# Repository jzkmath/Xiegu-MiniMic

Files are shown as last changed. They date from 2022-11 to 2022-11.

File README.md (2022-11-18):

# Xiegu-MiniMic
A Small Microphone for the Xiegu G90, X5105 and X6100 Radios. I have designed this to be assembled mostly by JLCPCB. (See below for instructions on how to order them)

After looking at the larger Microphone that comes with the radio, it appears to be a clone of the ICOM HM151 Hand Mic. Knowing this, I was able to use the service manual to create this PCB.

This is designed using KiCad Version 6.0.9

The Enclosure can be 3D Printed and requires 4 M2x20mm Socket Head Screws and 4 M2 Nuts. I used McMaster Carr Part numbers 91292A013 and 90591A111 for this project.

## Version History:

Rev. A: Initial Design

Rev. B: Found that the EM6022P Microphone Element was wired backwards. Fixed it in this revision.

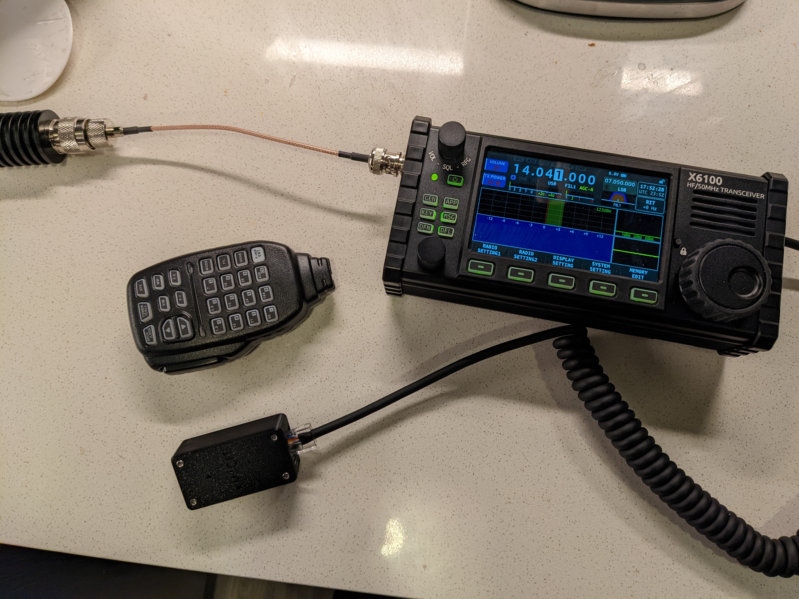
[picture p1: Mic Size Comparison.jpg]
Mic Size Comparison


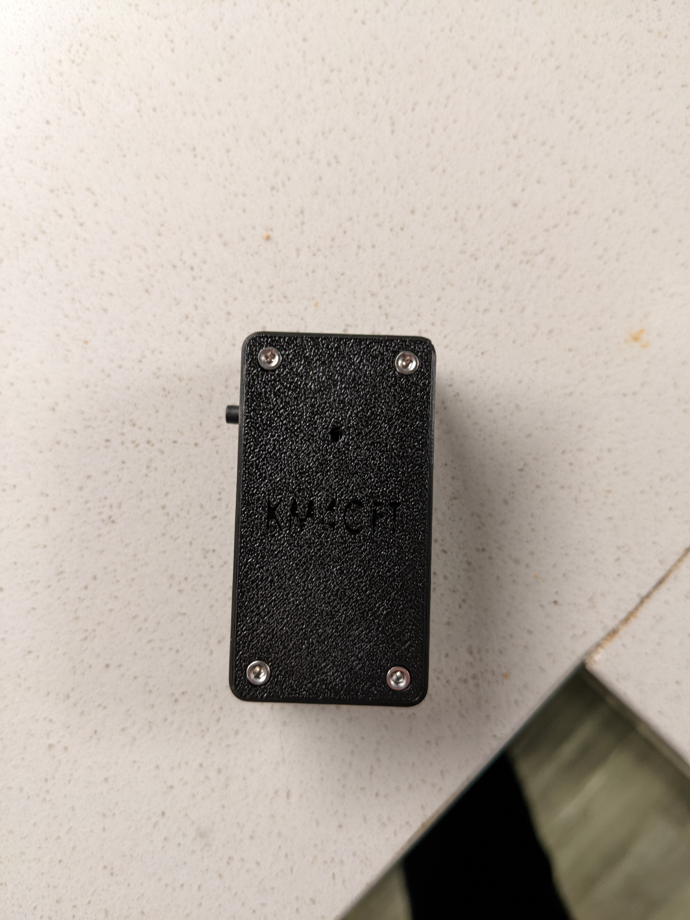
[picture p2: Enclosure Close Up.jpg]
Enclosure Close up


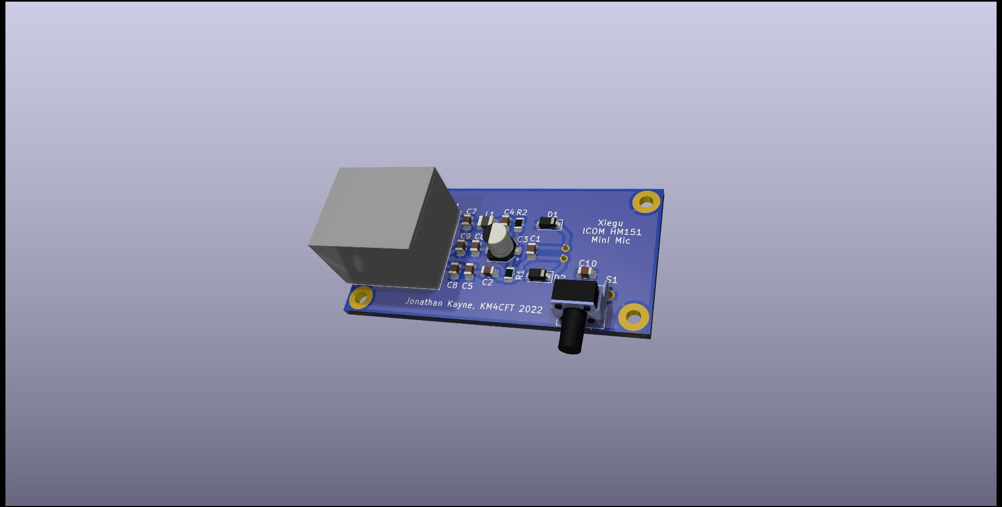
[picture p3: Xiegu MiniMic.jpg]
PCB Render


## PCB Assembly Instructions:

1. Download this repository by clicking on "code" then downloading as a ZIP file. Extract the ZIP file.
2. Go to https://jlcpcb.com/quote
3. Click "Add Gerber File" upload the `Xiegu-MiniMic-GERBER.zip` file found in the `GERBER` folder.
4. Adjust settings. The only ones you should change (if you want) is PCB Qty, PCB Color, and Surface Finish. 
  - If you just want the PCB you may click "Save to Cart" and place your order.
  - If you want assembly, proceed to step 5.
5. Scroll don and tick the slider to the right of "PCB Assembly"
6. Leave it set to "Assemble Top Side" and click "Confirm"
7. For the "BOM File" upload `Xiegu MiniMic.csv` in the `ASSEMBLY` folder.
8. For the "CPL File" upload `Xiegu MiniMic-top-pos.csv` in the `ASSEMBLY` folder.
9. For Usage, I recommend you set it to "Research/Education/DIY/Entertainment > DIY HS Code 902300" (You can really set it to whatever you want)
10. Click "Next"
11. Make sure the BOM is complete (except for the RJ45 connector) 
  - If one of the parts are out of stock, you can substitute with a similar part. 
  - For resistors and capacitors, the main thing to ensure is the value and the case is 0805 (except for C3)
  - C3 is an electrolytic capacitor. Specs needed: 10uF, at least 16V, Diameter: 4mm, Length: 5.4mm (SMD)
  - Zener Diodes are 9.1v, and have a SOD-123 package
  - Inductor L1 is 33uH and has a 1008 package size
12. Once any substitutions are made, click "Next"
13. Inspect the render to make sure the orientation is correct. C3 should have the plus line up and the diodes should have their negative on the right side, matching up with the silkscreen.
14. Click "Add to Cart" then place your order.

You will likely need to order the RJ45 connector (54602-908LF) and microphone (EM6022P) from Digikey or Mouser and solder them yourself.

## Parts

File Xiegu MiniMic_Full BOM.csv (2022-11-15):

Item | Qty | Reference(s) | Value | LibPart | Footprint | Digikey PN | LCSC | MPN | Manufacturer
1 | 1 | C1 | 470pF | Device:C | Capacitor_SMD:C_0805_2012Metric | 478-1324-1-ND | C1743 | 08055A471JAT2A | KYOCERA AVX
2 | 1 | C2 | 1uF | Device:C | Capacitor_SMD:C_0805_2012Metric | 478-5034-1-ND | C28323 | 0805YC105KAT2A | KYOCERA AVX
3 | 1 | C3 | 10uF | Device:C_Polarized_US | Capacitor_SMD:CP_Elec_4x5.4 | 493-2173-1-ND | C445074 | UWT1C100MCL1GB | Nichicon
4 | 3 | C4, C5, C6 | 22pF | Device:C | Capacitor_SMD:C_0805_2012Metric | 478-1308-1-ND | C1804 | 08055A220JAT2A | KYOCERA AVX
5 | 2 | C7, C10 | 100nF | Device:C | Capacitor_SMD:C_0805_2012Metric | 478-10836-1-ND | C28233 | 08055C104KAT4A | KYOCERA AVX
6 | 2 | C8, C9 | 4.7nF | Device:C | Capacitor_SMD:C_0805_2012Metric | 478-08055C472K4T4ACT-ND | C1744 | 08055C472K4T4A | KYOCERA AVX
7 | 2 | D1, D2 | MMSZ5239B-7-F | Device:D_Zener_Filled | Diode_SMD:D_SOD-123 | MMSZ5239B-FDICT-ND | C459546 | MMSZ5239B-7-F | Diodes Incorporated
8 | 4 | H1, H2, H3, H4 | M2 | Mechanical:MountingHole_Pad | MountingHole:MountingHole_2.2mm_M2_Pad
9 | 1 | J1 | 54602-908LF | Connector:8P8C | Connector_RJ:RJ45_Amphenol_54602-x08_Horizontal | 609-1046-ND | N/A | 54602-908LF | Amphenol ICC (FCI)
10 | 1 | L1 | 33uH | Device:L | Inductor_SMD:L_1008_2520Metric | 445-16476-1-ND | C295130 | NLV25T-330J-EF | TDK Corporation
11 | 1 | MK1 | EM6022P | Device:Microphone_Condenser | Xiegu MiniMic:EM6022P | 433-1088-ND | N/A | EM-6022P | Soberton Inc.
12 | 2 | R1, R2 | 2.2k | Device:R | Resistor_SMD:R_0805_2012Metric | A106060CT-ND | C2073912 | CRG0805F2K2 | TE Connectivity Passive Product
13 | 1 | S1 | 1-1825027-1 | Xiegu MiniMic:1-1825027-1 | Xiegu MiniMic:SW_1-1825027-1 | 450-1658-ND | C266183 | 1-1825027-1 | TE Connectivity ALCOSWITCH Switches

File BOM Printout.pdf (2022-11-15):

### Xiegu MiniMic BOM

Item | Qty Reference(s) Value | | Digikey PN | LCSC PN | MPN | Manufacturer
1 | 1 C1 | 470pF | 478-1324-1-ND | C1743 | 08055A471JAT2A | KYOCERA AVX
2 | 1 C2 | 1uF | 478-5034-1-ND | C28323 | 0805YC105KAT2A | KYOCERA AVX
3 | 1 C3 | 10uF | 493-2173-1-ND | C445074 | UWT1C100MCL1GB Nichicon
4 | 3 C4, C5, C6 | 22pF | 478-1308-1-ND | C1804 | 08055A220JAT2A | KYOCERA AVX
5 | 2 C7, C10 | 100nF | 478-10836-1-ND | C28233 | 08055C104KAT4A | KYOCERA AVX
6 | 2 C8, C9 | 4.7nF | 478-08055C472K4T4ACT-ND | C1744 | 08055C472K4T4A | KYOCERA AVX
7 | 2 D1, D2 | MMSZ5239B-7-F | MMSZ5239B-FDICT-ND | C459546 | MMSZ5239B-7-F | Diodes Incorporated
9 | 1 J1 | 54602-908LF | 609-1046-ND | N/A | 54602-908LF | Amphenol ICC (FCI)
10 | 1 L1 | 33uH | 445-16476-1-ND | C295130 | NLV25T-330J-EF | TDK Corporation
11 | 1 MK1 | EM6022P | 433-1088-ND | N/A | EM-6022P | Soberton Inc.
12 | 2 R1, R2 | 2.2k | A106060CT-ND | C2073912 | CRG0805F2K2 | TE Connectivity Passive Product
13 | 1 S1 | 1-1825027-1 | 450-1658-ND | C266183 | 1-1825027-1 | TE Connectivity ALCOSWITCH

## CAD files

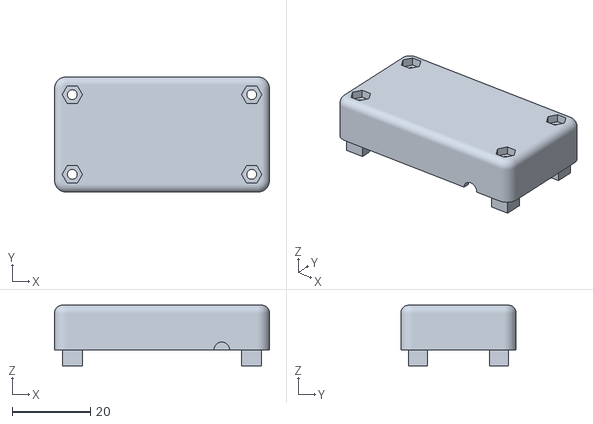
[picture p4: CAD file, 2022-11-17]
Enclosure/Xiegu MiniMic_Top.STL
54.8 x 29.4 x 15.5

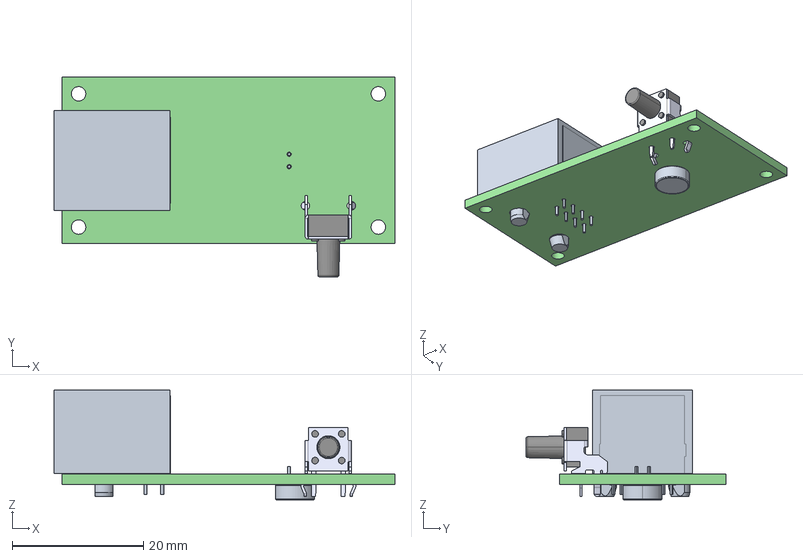
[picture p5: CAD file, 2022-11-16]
Xiegu MiniMic.step
52.0 x 30.4 x 16.7 mm
Xiegu MiniMic PCB

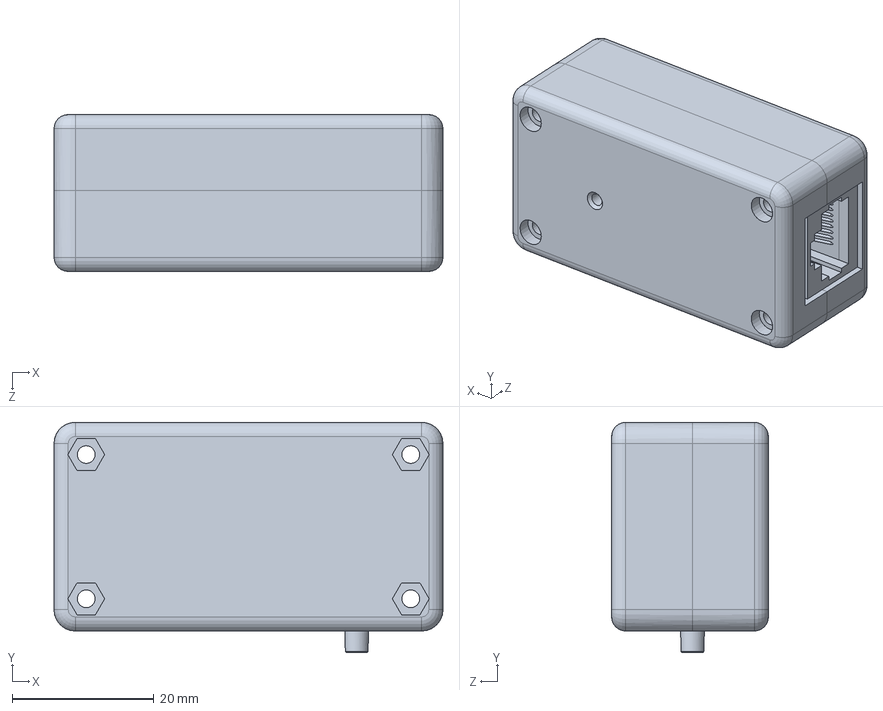
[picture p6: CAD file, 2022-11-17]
Enclosure/Xiegu MiniMic.SLDPRT
54.8 x 32.4 x 22.1 mm

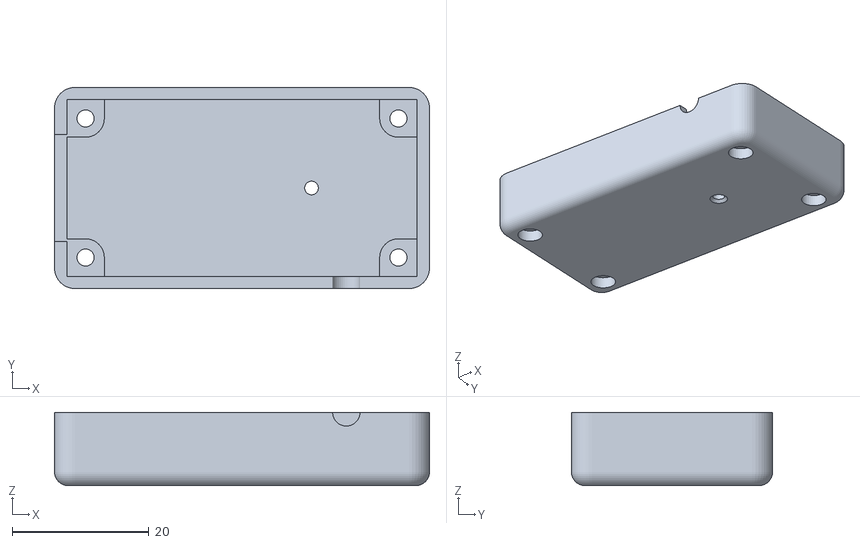
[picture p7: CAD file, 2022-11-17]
Enclosure/Xiegu MiniMic_Bottom.STL
54.8 x 29.4 x 10.7

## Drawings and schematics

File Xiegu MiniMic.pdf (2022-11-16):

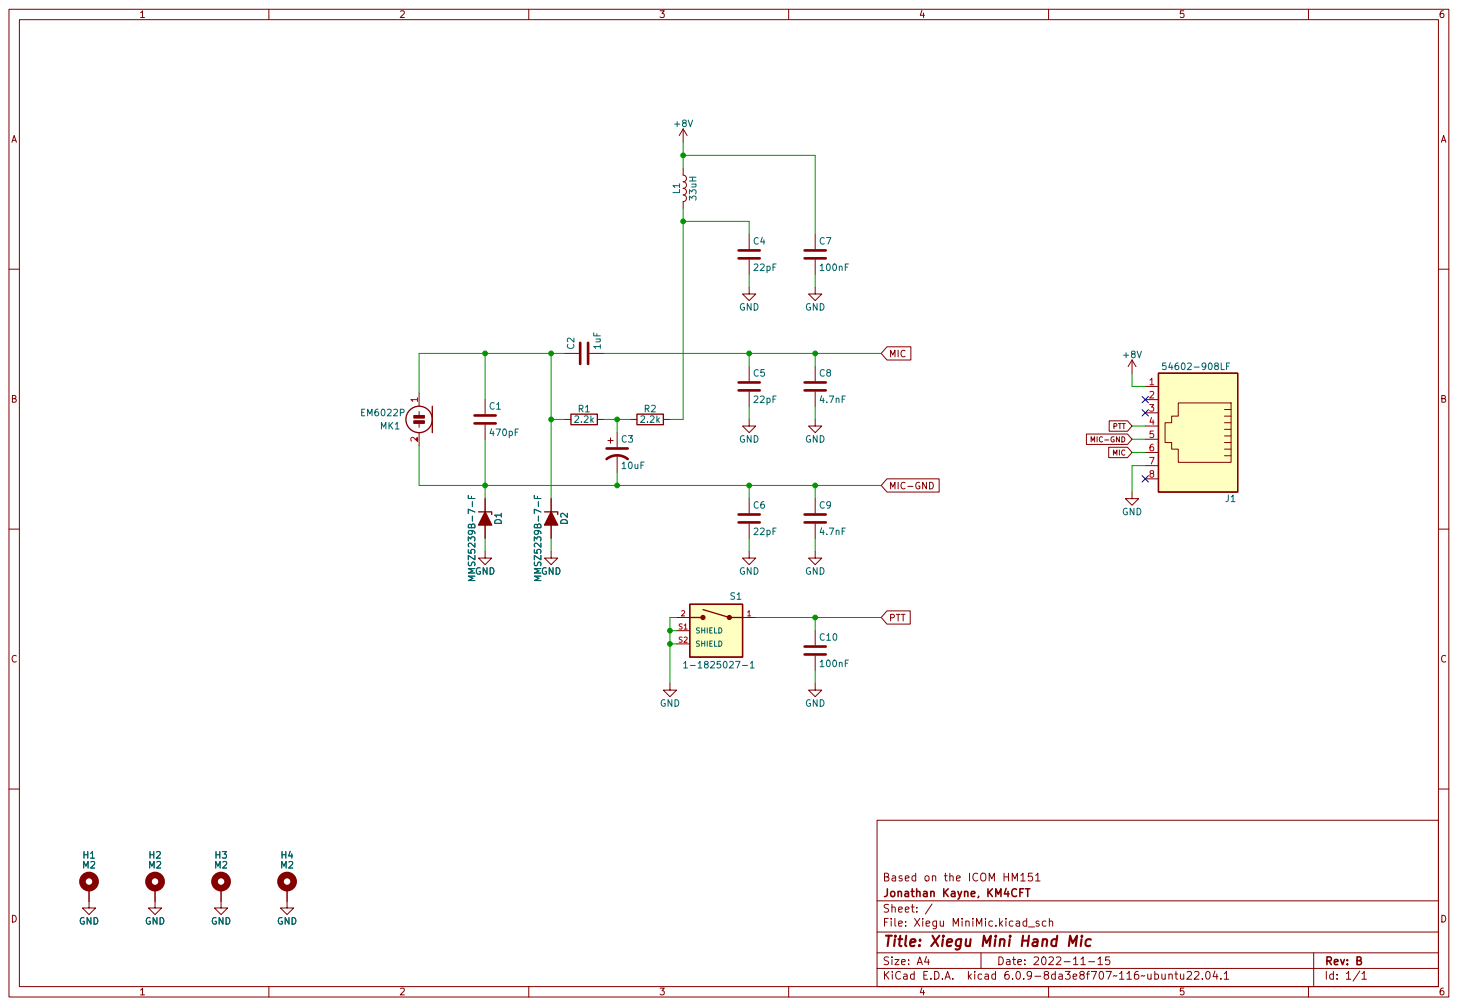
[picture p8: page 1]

PTT MIC-GND MIC

1 2 MK1 EM6022P D1 MMSZ5239B-7-F GND GND GND GND GND GND

Id: 1/1 Title: Xiegu Mini Hand Mic

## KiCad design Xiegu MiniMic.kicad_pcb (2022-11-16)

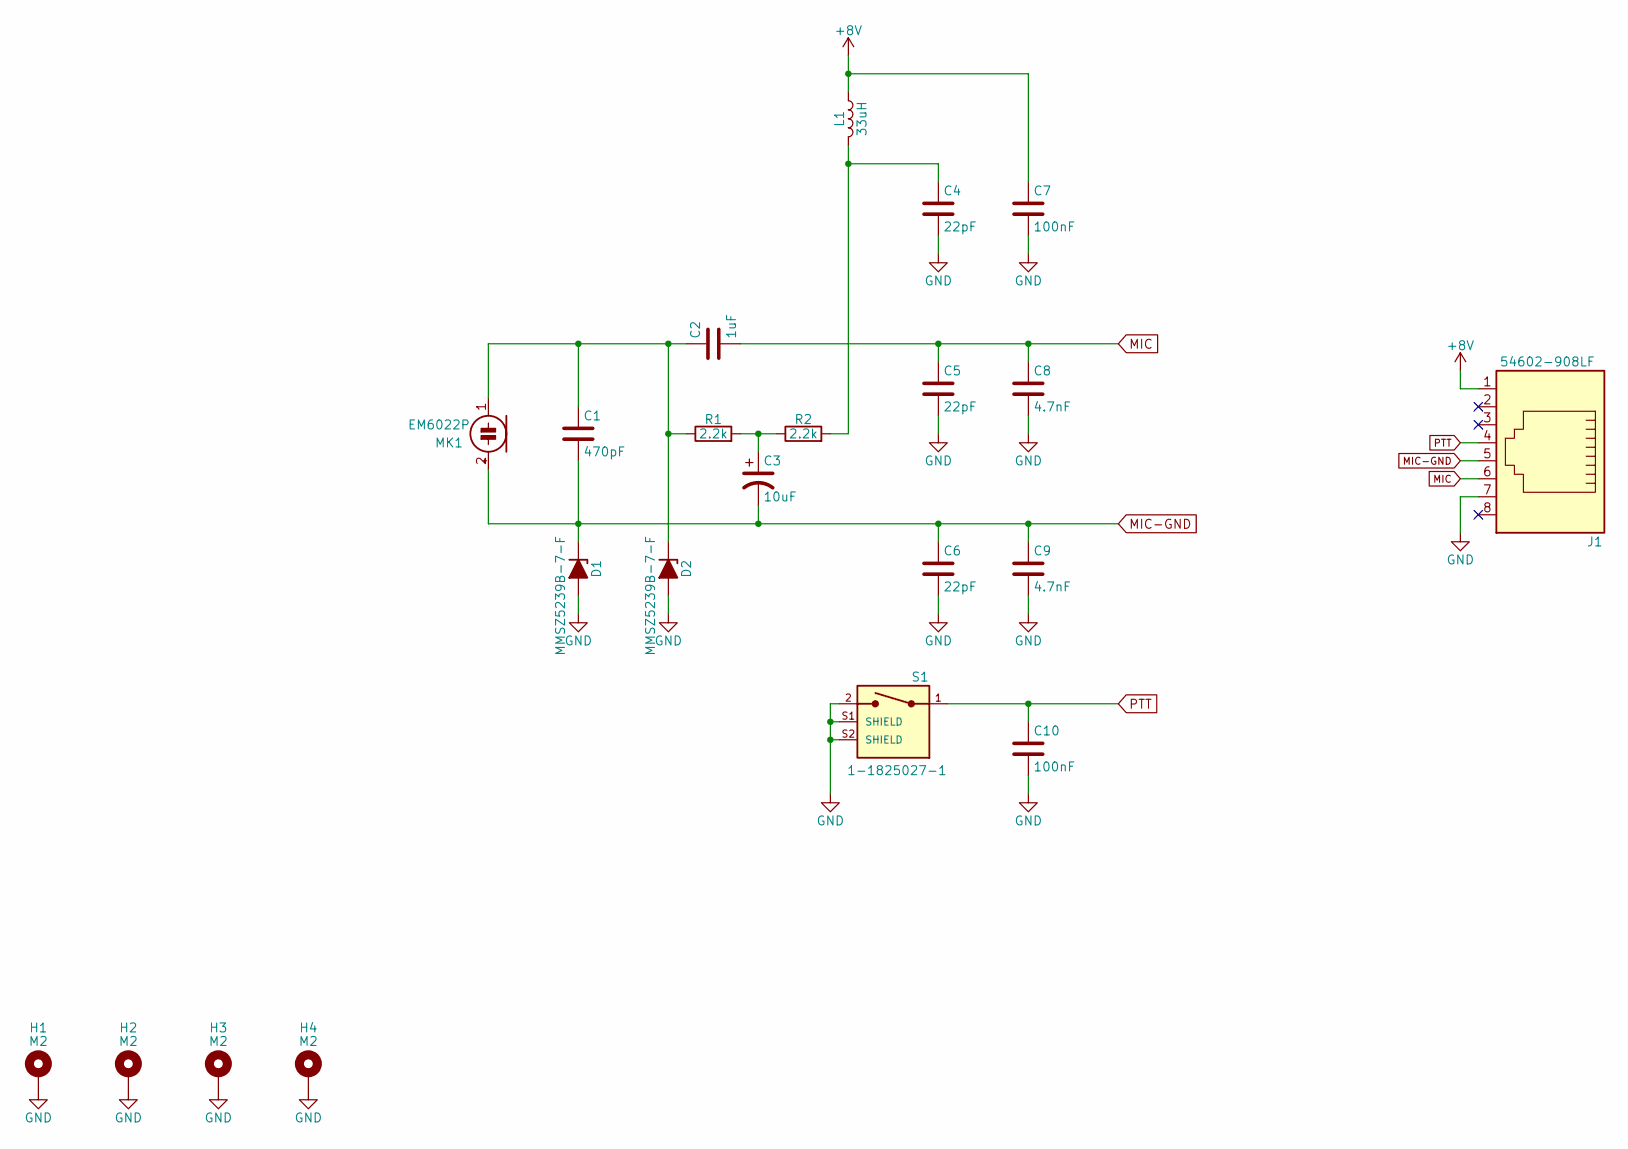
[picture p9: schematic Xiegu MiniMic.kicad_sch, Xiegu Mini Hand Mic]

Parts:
C1: 470pF; C_0805_2012Metric; MPN 08055A471JAT2A; Digikey PN 478-1324-1-ND
C2: 1uF; C_0805_2012Metric; MPN 0805YC105KAT2A; Digikey PN 478-5034-1-ND
C3: 10uF; CP_Elec_4x5.4; MPN UWT1C100MCL1GB; Digikey PN 493-2173-1-ND
C4, C5, C6: 22pF; C_0805_2012Metric; MPN 08055A220JAT2A; Digikey PN 478-1308-1-ND
C7, C10: 100nF; C_0805_2012Metric; MPN 08055C104KAT4A; Digikey PN 478-10836-1-ND
C8, C9: 4.7nF; C_0805_2012Metric; MPN 08055C472K4T4A; Digikey PN 478-08055C472K4T4ACT-ND
D1, D2: MMSZ5239B-7-F; D_SOD-123; MPN MMSZ5239B-7-F; Digikey PN MMSZ5239B-FDICT-ND
H1, H2, H3, H4: M2; MountingHole_2.2mm_M2_Pad
J1: 54602-908LF; RJ45_Amphenol_54602-x08_Horizontal; MPN 54602-908LF; Digikey PN 609-1046-ND
L1: 33uH; L_1008_2520Metric; MPN NLV25T-330J-EF; Digikey PN 445-16476-1-ND
MK1: EM6022P; MPN EM-6022P; Digikey PN 433-1088-ND
R1, R2: 2.2k; R_0805_2012Metric; MPN CRG0805F2K2; Digikey PN A106060CT-ND
S1: 1-1825027-1; SW_1-1825027-1; MPN 1-1825027-1; Digikey PN 450-1658-ND

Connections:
+8V: C7.1, J1.1, L1.1
GND: C4.2, C5.2, C6.2, C7.2, C8.2, C9.2, C10.2, D1.2 (A), D2.2 (A), H1.1, H2.1, H3.1, H4.1, J1.7, S1.2, S1.S1 (SHIELD), S1.S2 (SHIELD)
MIC: C2.2, C5.1, C8.1, J1.6
MIC-GND: C1.2, C3.2, C6.1, C9.1, D1.1 (K), J1.5, MK1.2 (+)
unnamed: C1.1, C2.1, D2.1 (K), MK1.1 (-), R1.1
unnamed: C3.1, R1.2, R2.1
unnamed: C4.1, L1.2, R2.2
PTT: C10.1, J1.4, S1.1

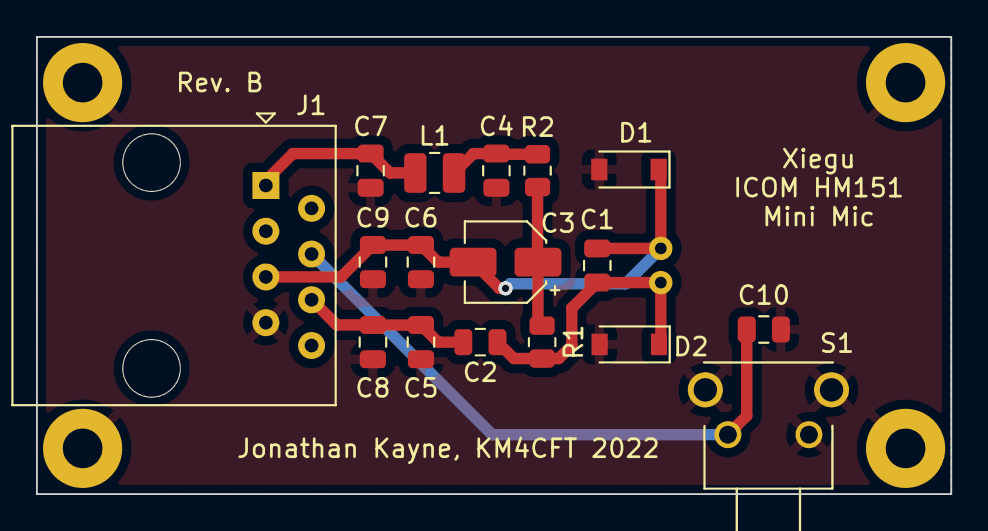
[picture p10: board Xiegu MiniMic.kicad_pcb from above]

Board: 2 copper layers, 50.8 x 25.4 mm, 22 parts (1 on the bottom side), 8 nets.

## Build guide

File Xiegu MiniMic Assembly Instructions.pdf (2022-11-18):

### Xiegu MiniMic Soldering Tips

Jonathan Kayne, KM4CFT
The purpose of this document is to provide some tips and tricks for soldering the Xiegu MiniMic. These will also be useful for any additional Surface-Mount Soldering you may do in the future.
Ultimately, SMD Soldering can be easily performed if you follow these rules:

### 1. More Heat 2. Less Solder 3. Flux is Magic 4. Use Magnification

You will want to have some thin solder, tweezers, a flux pen (I recommend the “no clean” variety) and a cotton swab. Additionally, you may want some type of brush to wipe off the flux residue (no clean flux leaves behind a powder that you can brush off the PCB). The cotton swab is useful because you can use the blunt end of the swab to help the component lie flat.

The process for soldering and SMD component is as follows:
1. Add a small amount of solder to one pad. If possible, avoid starting with the ground pad, since the ground pad requires more heat to solder than a non-grounded pad. Grounded pads have a plus shape on them.
2. Using your tweezers and soldering iron, melt the solder and carefully move the component into place. Try to get it centered if you can!
a) When holding your tweezers, you should avoid holding them like a pencil. You want to “pinch” the tweezers in a way where all 5 fingers are touching it. The advantage to this method is that you can place your fingertips against the table while holding the tweezers and thus make your hand more steady:

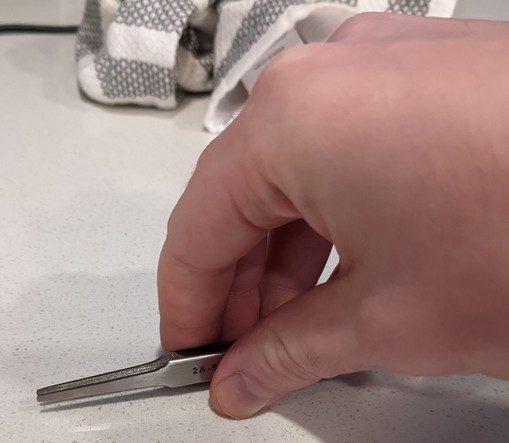
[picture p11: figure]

3. Place the blunt end of the swab on top of the component and reflow the solder. The purpose of this is to make sure that the component is lying flat against the board:

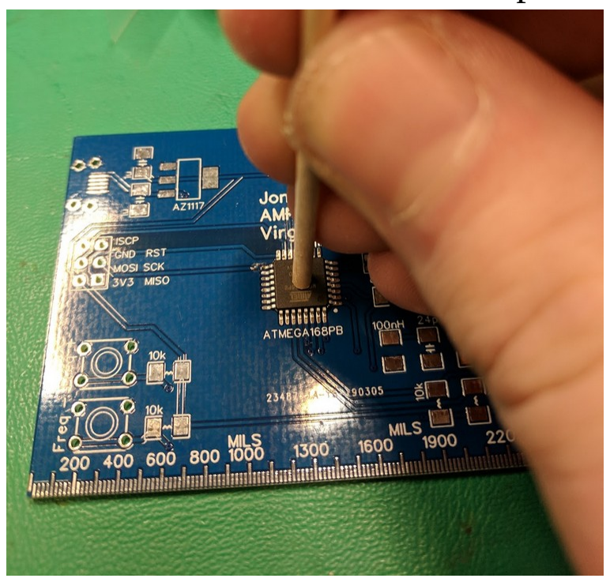
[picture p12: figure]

4. Solder the other pad. Remember rule number 2!
5. Using the flux pen, soak the two ends in flux and reflow the solder. You should observe the flux hiss then the solder melt.
6. (optional) Use a brush to wipe away any flux residue. Once you finish assembly you can also carefully rinse the board in rubbing alcohol to clean away any leftover residue.

### IMPORTANT NOTE:

If your board is Revision A, you will need to solder the EM6022P Microphone element backwards like in this picture:

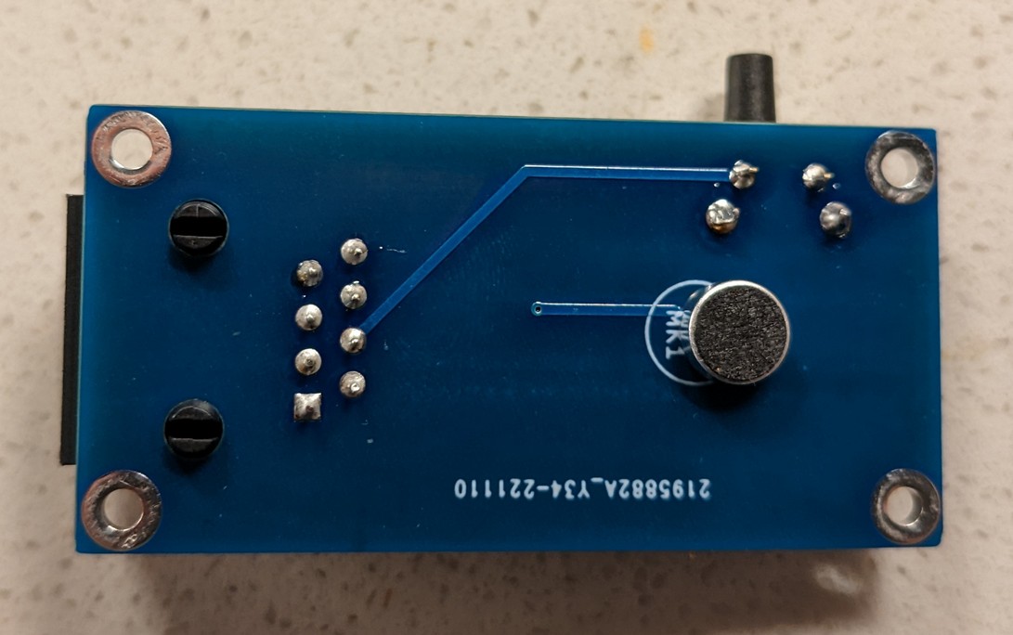
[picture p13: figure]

If you have Revision B, then solder it in the expected orientation.
- For assembly, I have an interactive BOM in the project GitHub that you can use to track which parts you have soldered on.
- You can solder these in any order but I recommend saving the switch, RJ45 connector and mic for last.

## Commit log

2022-11-16 Rev B
    [Xiegu MiniMic.kicad_pcb, Xiegu MiniMic.kicad_sch, Xiegu MiniMic.step]
2022-11-17 Fixed hardware tolerance
    [Xiegu MiniMic.SLDPRT, Xiegu MiniMic_Bottom.STL, Xiegu MiniMic_Top.STL]
2022-11-18 added PCB assembly instructions
